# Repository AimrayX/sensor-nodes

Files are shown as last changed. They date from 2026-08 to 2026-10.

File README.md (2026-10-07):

# sensor-nodes

ESP32-based environmental sensor nodes for home automation, publishing MQTT state updates for room-level monitoring.

This project is designed for a small cluster of battery/USB-powered ESP32-C6 nodes that measure indoor or outdoor conditions and report them to an MQTT broker for use in dashboards, automations, or home assistant-style workflows.

## Features

- ESP32-C6 firmware built with PlatformIO and Arduino
- MQTT publishing over Wi-Fi
- OTA firmware updates for selected nodes
- Watchdog-based reboot protection for silent failures
- Support for multiple sensor combinations in separate build environments
- Native host-side unit tests for payload logic

## Hardware configurations

The repository currently includes two primary node variants:

### 1. Bedroom node: BME688 + SCD41

- BME688 environmental sensor
- SCD41 CO2 sensor
- Publishes to: `flat/bedroom/state`
- Build target: `node_bme688_scd41`
- OTA target: `node_bme688_scd41_ota`

### 2. Balcony node: BME280 + PMSA003I

- BME280 temperature / humidity / pressure sensor
- PMSA003I particulate matter sensor
- Publishes to: `flat/balcony/state`
- Build target: `node_pmsa_bme280`
- OTA target: `node_pmsa_bme280_ota`

## Project structure

```text
.
├── .vscode/
├── include/
├── lib/
├── src/
│   ├── connection_handler.cpp
│   ├── connection_handler.h
│   ├── i2c_scanner.cpp
│   ├── main.cpp
│   ├── ota_handler.cpp
│   ├── ota_handler.h
│   ├── payload.cpp
│   ├── payload.h
│   ├── sensors.h
│   ├── sensors_bme280_pmsa003i.cpp
│   ├── sensors_bme688_scd41.cpp
│   ├── watchdog.cpp
│   └── watchdog.h
├── test/
├── .gitignore
├── LICENSE
├── README.md
├── platformio.ini
└── ...
```

## Build and run

### Prerequisites

- PlatformIO Core or VS Code + PlatformIO extension
- An ESP32-C6 compatible board
- Appropriate sensor hardware wired to the board
- A Wi-Fi network and MQTT broker

### Install dependencies

```bash
pio pkg install
```

### Build a specific environment

```bash
pio run -e node_bme688_scd41
pio run -e node_pmsa_bme280
```

### Upload over USB

```bash
pio run -e node_bme688_scd41 -t upload
pio run -e node_pmsa_bme280 -t upload
```

### OTA upload

For OTA builds, create an environment variable with your password before flashing:

```bash
export OTA_PASS="your-ota-password"
pio run -e node_bme688_scd41_ota -t upload
pio run -e node_pmsa_bme280_ota -t upload
```

The project sets OTA host names in `platformio.ini` using the node names:

- `bedroom.local`
- `balcony.local`

## MQTT and node behavior

Each node publishes a structured reading containing the values currently available from its sensors. The common payload model includes:

- PM1, PM2.5, PM10
- CO2
- temperature
- humidity
- pressure

The firmware loops on a 30-second publish interval and reboots after 30 minutes without a successful publish to recover from persistent communication faults.

## Configuration notes

The environment-specific settings live in `platformio.ini` and define:

- board type (`esp32-c6-devkitc-1`)
- sensor libraries
- MQTT topic names
- OTA upload parameters
- build filters for each node variant

Example topic definitions:

```ini
-D NODE_TOPIC='"flat/bedroom/state"'
-D NODE_NAME='"bedroom"'
```

## Testing

The project includes a native host build for unit testing payload logic without a physical board.

```bash
pio test -e native
```

## License

This project is licensed under the GNU General Public License v2.0. See the [LICENSE](LICENSE) file for details.

## Notes

- The `scanner` environment is intended for I2C bus diagnostics during bring-up.
- The `native` environment is helpful for validating logic that does not require board hardware.
- The firmware is intended for local home automation and experimentation, and is configured to fit a small ESP32 sensor network rather than a generic IoT platform.

## Example usage

Once the devices are online, you can subscribe to the topic stream and integrate the readings into dashboards or automation logic.

```bash
mosquitto_sub -h localhost -t 'flat/+/state'
```

This gives you a simple MQTT data source for climate, air quality, and room-state monitoring.

## Repository

- GitHub: https://github.com/AimrayX/sensor-nodes
- Description: ESP32 cluster with environment sensors for home automation via MQTT

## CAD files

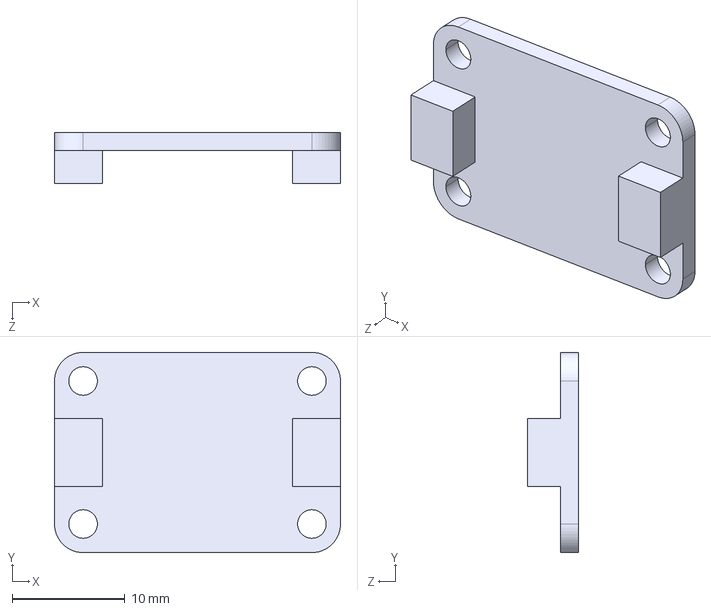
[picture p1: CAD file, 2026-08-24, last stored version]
adafruit-bme688-1.snapshot.2/Adafruit BME688.STEP
25.4 x 17.8 x 4.51 mm

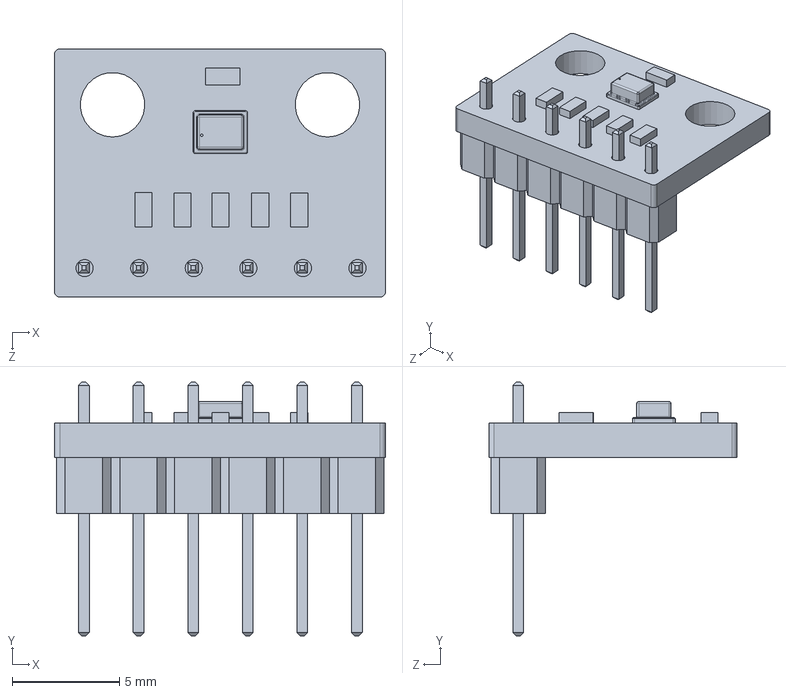
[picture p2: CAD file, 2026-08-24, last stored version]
bme280-model-1.snapshot.2/BME280_SENSOR_MODULE/BME280_SENSOR_MODULE.SLDPRT
15.4 x 11.8 x 11.6 mm

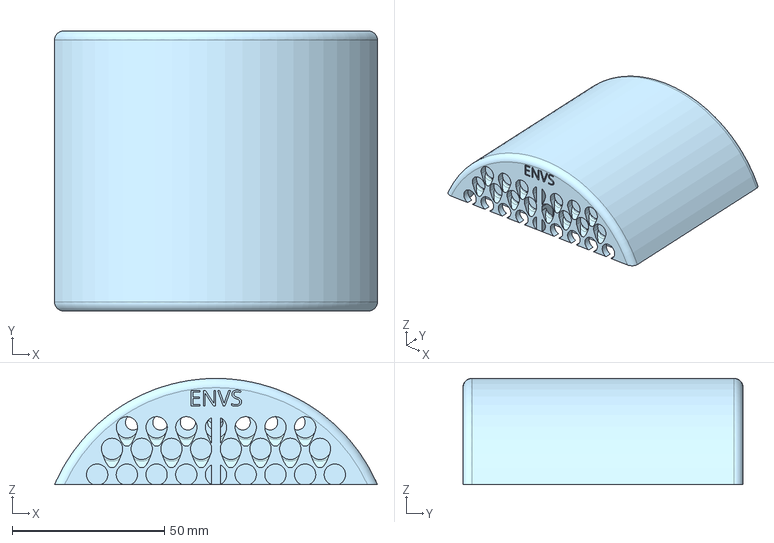
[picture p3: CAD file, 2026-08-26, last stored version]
caseV1.step
106.0 x 92.0 x 34.8 mm

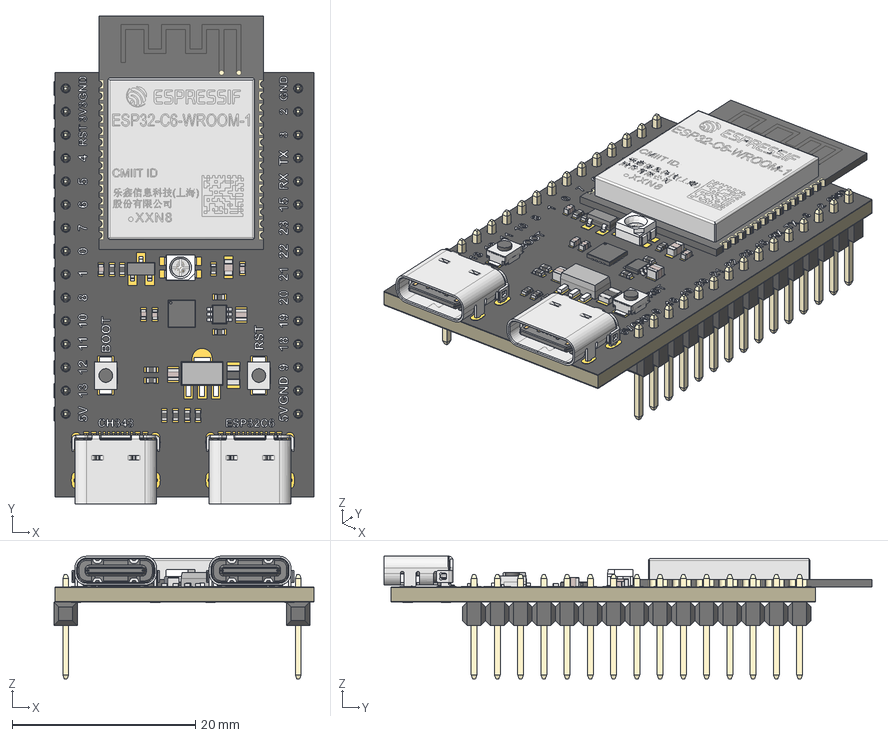
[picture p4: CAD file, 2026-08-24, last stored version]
esp32-c6-wroom-1-1.snapshot.2/ESP32C6.step
28.4 x 53.3 x 13.4 mm
ESP32-C6-WROOM
Chip a 6 pattes
Board
64-copper
1-soldermask
64-soldermask
B3U-1000P(M) v3 x 2
629722000214_Housing x 2
629722000214_Pin1_Top x 2
629722000214_Pin4_Bottom x 2
629722000214_Pin4_Top x 4
629722000214_Pin1_Bottom x 2
629722000214_Pin3_Bottom x 2
629722000214_Pin3_Top x 2
629722000214_Pin2_Top x 2
629722000214_Pin2_Bottom x 2
629722000214_Pin1_Top_mir x 2
629722000214_Pin1_Bottom_mir x 2
629722000214_Pin2_Top_mir x 2
629722000214_Pin2_Bottom_mir x 2
629722000214_Pin3_Top_mir x 2
629722000214_Pin3_Bottom_mir x 2
629722000214_Pin4_Bottom_mir x 2
629722000214_Shielding2 x 2
629722000214_Shielding x 2
9216695.f3d x 4
9216912.f3d x 2
9216932.f3d
5576505.f3d x 11
5576561.f3d
cover
housing
base x 2
SOT89
SOT23
1-copper
Silkscreen

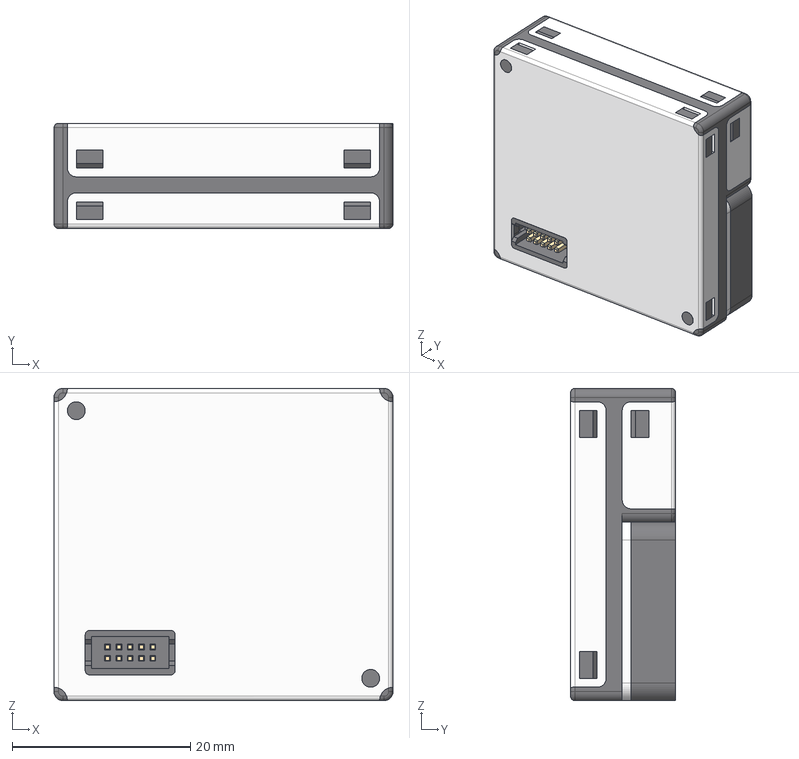
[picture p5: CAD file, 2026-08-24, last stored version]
plantower-pmsa003i-digital-laser-dust-sensor-1.snapshot.2/PM2.5 Air Quality Sensor with I2C Interface - PMSA003I v7.step
38.0 x 11.8 x 35.0 mm

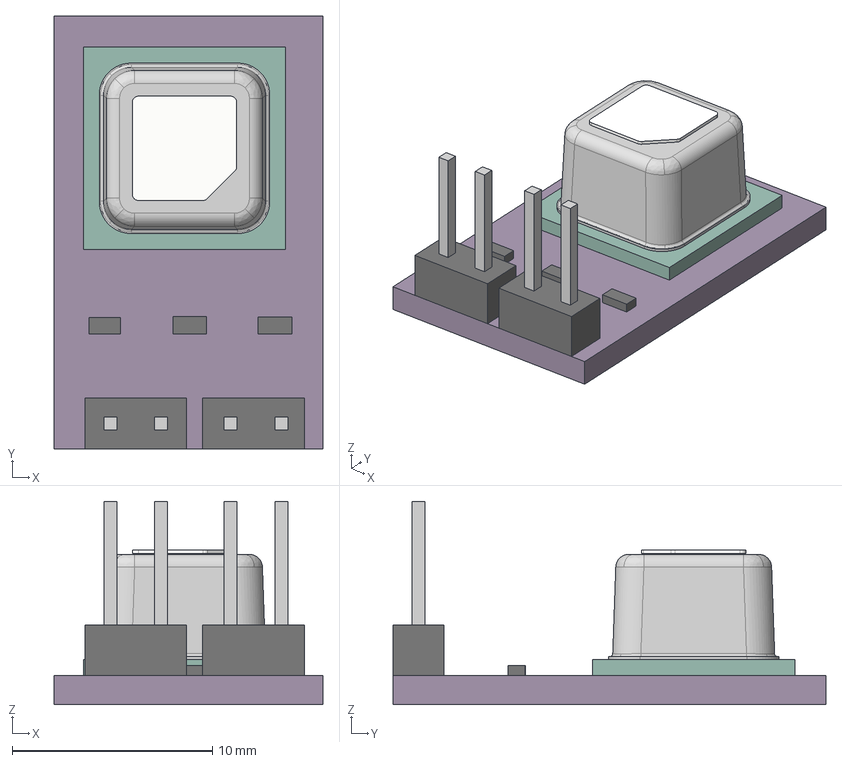
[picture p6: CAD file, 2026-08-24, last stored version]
sensirion-scd40-scd41-1.snapshot.26/scd40 v7.step
13.4 x 21.6 x 10.1 mm
Komponente1
Komponente1 (1)
Komponente2
Komponente3

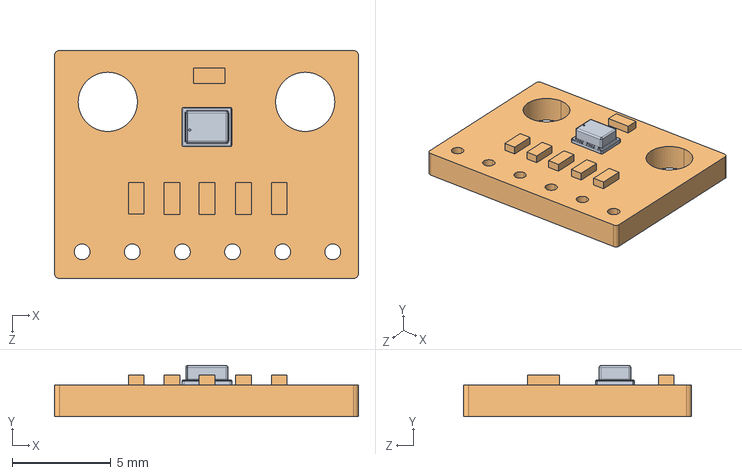
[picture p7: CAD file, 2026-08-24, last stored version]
bme280-model-1.snapshot.2/BME280_SENSOR_MODULE.STEP
15.4 x 2.60 x 11.6 mm

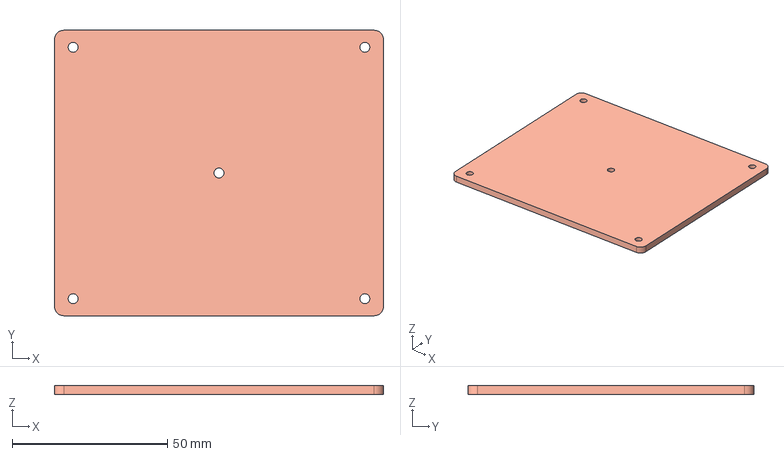
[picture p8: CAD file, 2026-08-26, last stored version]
lidV1.step
106.0 x 92.0 x 3.00 mm

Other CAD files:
bme280-model-1.snapshot.2/BME280_SENSOR_MODULE_WITH_HEADER.STEP
lid.step
case.step
adafruit-bme688-1.snapshot.2/Adafruit BME688.SLDPRT
plantower-pmsa003i-digital-laser-dust-sensor-1.snapshot.2/PM2.5 Air Quality Sensor with I2C Interface - PMSA003I v7.stl
sensirion-scd40-scd41-1.snapshot.26/scd40 v7.3mf

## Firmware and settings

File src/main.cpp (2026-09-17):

#include <Arduino.h>
#include <Wire.h>
#include <esp_task_wdt.h>
#include <esp_system.h>

#include "sensors.h"
#include "connection_handler.h"
#include "ota_handler.h"
#include "watchdog.h"

static constexpr unsigned long PUBLISH_INTERVAL_MS = 30000;
static constexpr unsigned long MAX_SILENCE_MS = 30UL * 60UL * 1000UL;

static unsigned long lastGoodPublish = 0;

void setup() {
  Serial.begin(115200);
  while (!Serial && millis() < 5000) delay(10);
  delay(500);
  Serial.printf("%s booting, reset reason %d\n", NODE_NAME, esp_reset_reason());

  Wire.begin(SDA, SCL);
  if (!sensors_init(Wire)) Serial.println("sensors_init reported failure");

  connection_init();
  ota_init(NODE_NAME);
  watchdog_init();
  lastGoodPublish = millis();

  Serial.printf("TWDT subscribed: %s\n",
                esp_task_wdt_status(NULL) == ESP_OK ? "yes" : "NO");
}

void loop() {
  ota_loop();
  if (ota_in_progress()) return;

  esp_task_wdt_reset();
  connection_loop();
  sensors_tick();

  static unsigned long lastMsg = 0;
  unsigned long now = millis();

  if (now - lastMsg > PUBLISH_INTERVAL_MS) {
    lastMsg = now;
    Reading r;
    if (sensors_read(r) && publish(NODE_TOPIC, r)) {
      lastGoodPublish = now;
      sensors_mark_sent();
    }
  }

  if (now - lastGoodPublish > MAX_SILENCE_MS) {
    Serial.println("30 min without a publish - rebooting");
    Serial.flush();
    delay(100);
    ESP.restart();
  }
}

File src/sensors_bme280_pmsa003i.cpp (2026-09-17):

#include "sensors.h"

#include <Adafruit_BME280.h>
#include <Adafruit_PM25AQI.h>

static Adafruit_BME280 bme;
static Adafruit_PM25AQI aqi = Adafruit_PM25AQI();
static bool bmeOk = false;
static bool aqiOk = false;

// The PM sensor is duty-cycled: the fan is the wear item, so it runs for
// ~38 s out of every 5 min. Wake -> WarmingUp (fan stabilises, output is
// not trustworthy) -> Sampling (poll repeatedly, keep the last good frame)
// -> Sleeping.
enum class PmState { Sleeping, WarmingUp, Sampling };
static PmState pmState = PmState::WarmingUp;

static unsigned long pmCycleStart = 0;  // when the current 5 min period began
static unsigned long pmPhaseStart = 0;  // when the current phase began
static unsigned long pmLastPoll   = 0;  // last aqi.read() attempt

static constexpr unsigned long PM_INTERVAL_MS = 5UL * 60UL * 1000UL;
static constexpr unsigned long PM_WARMUP_MS   = 30UL * 1000UL;
static constexpr unsigned long PM_SAMPLE_MS   = 8UL * 1000UL;
static constexpr unsigned long PM_POLL_MS     = 1000UL;
static constexpr uint8_t       PM_MIN_FRAMES  = 2;

static PM25_AQI_Data pmLastFrame;
static uint8_t       pmGoodFrames = 0;

static float pmCache1 = NAN, pmCache25 = NAN, pmCache10 = NAN;
static unsigned long pmCacheAt = 0;
static bool  pmFresh  = false;

bool sensors_init(TwoWire &wire) {
  pinMode(PIN_PM_SET, OUTPUT);
  digitalWrite(PIN_PM_SET, HIGH);
  delay(100);

  Serial.println(F("Setting up BME280"));

  bmeOk = bme.begin(BME280_ADDRESS, &wire);
  if (!bmeOk) bmeOk = bme.begin(BME280_ADDRESS_ALTERNATE, &wire);
  if (bmeOk) {
    // Forced mode at 30 s intervals, so power is irrelevant - buy noise
    // reduction with oversampling instead. IIR stays OFF: in forced mode
    // the filter state persists between measurements, so with a 30 s gap
    // it would smear temperature over several minutes, and temperature is
    // a control input.
    bme.setSampling(Adafruit_BME280::MODE_FORCED,
                    Adafruit_BME280::SAMPLING_X2,   // temperature
                    Adafruit_BME280::SAMPLING_X16,  // pressure
                    Adafruit_BME280::SAMPLING_X16,  // humidity
                    Adafruit_BME280::FILTER_OFF);
  } else {
    Serial.println("Could not find a valid BME280 sensor, check wiring!");
  }

  Serial.println("BME280 setup finished");
  Serial.println();

  Serial.println(F("Setting up PMSA003I"));
  aqiOk = aqi.begin_I2C(&wire);
  if (!aqiOk) {
    Serial.println("Could not find PMSA003I sensor, check wiring!");
  }
  Serial.println("PMSA003I setup finished");
  Serial.println();

  // Start in WarmingUp so the first reading arrives ~38 s after boot
  pmCycleStart = millis();
  pmPhaseStart = millis();
  pmState = PmState::WarmingUp;

  // Degrade rather than fail: temperature/humidity/pressure alone is still
  // a useful node. PM availability is reported separately above.
  return bmeOk;
}

void sensors_tick() {
  const unsigned long now = millis();

  switch (pmState) {
    case PmState::Sleeping:
      if (now - pmCycleStart >= PM_INTERVAL_MS) {
        digitalWrite(PIN_PM_SET, HIGH);
        pmCycleStart = now;
        pmPhaseStart = now;
        pmState = PmState::WarmingUp;
      }
      break;

    case PmState::WarmingUp:
      if (now - pmPhaseStart >= PM_WARMUP_MS) {
        pmGoodFrames = 0;
        pmLastPoll   = now - PM_POLL_MS;  // poll immediately on entry
        pmPhaseStart = now;
        pmState      = PmState::Sampling;
      }
      break;

    case PmState::Sampling:
      // The module emits a frame about once per second; polling faster just
      // re-reads the same buffer and hogs the I2C bus shared with the BME280.
      if (now - pmLastPoll >= PM_POLL_MS) {
        pmLastPoll = now;
        PM25_AQI_Data d;
        if (aqiOk && aqi.read(&d)) {   // read() validates the checksum
          pmLastFrame = d;
          pmGoodFrames++;
        }
      }

      if (now - pmPhaseStart >= PM_SAMPLE_MS) {
        if (pmGoodFrames >= PM_MIN_FRAMES) {
          // _env is the atmospheric-environment output (vs _standard, CF=1).
          // Note the naming: pm10_env is PM1.0, pm100_env is PM10.
          pmCache1  = pmLastFrame.pm10_env;
          pmCache25 = pmLastFrame.pm25_env;
          pmCache10 = pmLastFrame.pm100_env;
          pmCacheAt = now;
          pmFresh   = true;
        } else {
          Serial.printf("PMSA003I: only %u good frame(s), skipping cycle\n",
                        pmGoodFrames);
        }
        digitalWrite(PIN_PM_SET, LOW);
        pmPhaseStart = now;
        pmState      = PmState::Sleeping;
      }
      break;
  }
}

bool sensors_read(Reading& out) {
  bool any = false;

  if (bmeOk) {
    if (bme.takeForcedMeasurement()) {
      out.temp     = bme.readTemperature();
      out.humidity = bme.readHumidity();
      out.pressure = bme.readPressure();
      any = true;
    } else {
      Serial.println("BME280 forced measurement failed");
    }
  }

  // Offered until sensors_mark_sent() confirms delivery, but never longer
  // than one cycle - a value older than that is superseded, not retried.
  if (pmFresh) {
    if (millis() - pmCacheAt < PM_INTERVAL_MS) {
      out.pm1  = pmCache1;
      out.pm25 = pmCache25;
      out.pm10 = pmCache10;
      any = true;
    } else {
      pmFresh = false;
    }
  }

  return any;
}

void sensors_mark_sent() {
  pmFresh = false;
}

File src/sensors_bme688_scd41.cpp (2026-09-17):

#include "sensors.h"

#include <Adafruit_BME680.h>
#include <SensirionI2cScd4x.h>

static Adafruit_BME680 bme(&Wire);
static SensirionI2cScd4x scd;

static bool bmeOk = false;
static bool scdOk = false;

static float co2Cache = NAN;
static unsigned long co2CacheAt = 0;
static bool  co2Fresh = false;

static unsigned long lastScdPoll = 0;
static constexpr unsigned long SCD_POLL_MS = 1000;
static constexpr unsigned long CO2_MAX_AGE_MS = 60UL * 1000UL;

bool sensors_init(TwoWire &wire) {
  Serial.println(F("Setting up BME688"));

  bmeOk = bme.begin(BME68X_DEFAULT_ADDRESS, true);   // 0x77
  if (!bmeOk) bmeOk = bme.begin(0x76, true);         // common alternate
  if (!bmeOk) {
    Serial.println("BME688 not found, continuing without it");
  } else {
    bme.setTemperatureOversampling(BME680_OS_2X);
    bme.setHumidityOversampling(BME680_OS_16X);
    bme.setPressureOversampling(BME680_OS_16X);
    bme.setIIRFilterSize(BME680_FILTER_SIZE_0);
    bme.setGasHeater(0, 0);   // gas heater off: no BSEC, no IAQ output
  }

  Serial.println("BME688 setup finished");
  Serial.println();

  Serial.println(F("Setting up SCD41"));

  scdOk = true;
  scd.begin(wire, 0x62);
  delay(30);

  scd.wakeUp();
  delay(30);

  if (scd.stopPeriodicMeasurement()) {
    Serial.println("SCD41 stopPeriodicMeasurement returned an error (ok if idle)");
  }
  delay(500);   // datasheet: stop takes up to 500 ms to complete

  if (scd.reinit()) {
    Serial.println("SCD41 reinit() failed");
    scdOk = false;
  }

  uint64_t serialNumber = 0;
  if (scd.getSerialNumber(serialNumber)) {
    Serial.println("SCD41 getSerialNumber() failed");
    scdOk = false;
  } else {
    Serial.printf("SCD41 serial number: %04X%04X%04X\n",
                  (unsigned)((serialNumber >> 32) & 0xFFFF),
                  (unsigned)((serialNumber >> 16) & 0xFFFF),
                  (unsigned)(serialNumber & 0xFFFF));
  }

  if (scd.startPeriodicMeasurement()) {
    Serial.println("SCD41 startPeriodicMeasurement() failed");
    scdOk = false;
  }

  Serial.println("SCD41 setup finished");
  Serial.println();

  // Degrade rather than fail, same as the BME280 variant.
  return bmeOk || scdOk;
}

void sensors_tick() {
  if (!scdOk) return;

  const unsigned long now = millis();
  if (now - lastScdPoll < SCD_POLL_MS) return;   // don't hammer the I2C bus
  lastScdPoll = now;

  bool ready = false;
  // Sensirion's generated drivers return int16_t, 0 == NO_ERROR.
  if (scd.getDataReadyStatus(ready) != 0 || !ready) return;

  uint16_t co2 = 0;
  float t = 0.0f, rh = 0.0f;
  if (scd.readMeasurement(co2, t, rh) == 0 && co2 != 0) {
    co2Cache   = co2;      // a CO2 of 0 means the sample is invalid
    co2CacheAt = now;
    co2Fresh   = true;
  }
}

bool sensors_read(Reading& out) {
  bool any = false;

  if (bmeOk) {
    if (bme.performReading()) {
      out.temp     = bme.temperature;
      out.humidity = bme.humidity;
      out.pressure = bme.pressure;
      any = true;
    } else {
      Serial.println("BME688 performReading() failed");
    }
  }

  // A new CO2 sample lands every 5 s, so retrying a failed publish matters
  // less here than for PM - but keep the interface identical across variants.
  if (co2Fresh) {
    if (millis() - co2CacheAt < CO2_MAX_AGE_MS) {
      out.co2 = co2Cache;
      any = true;
    } else {
      co2Fresh = false;
    }
  }

  return any;
}

void sensors_mark_sent() {
  co2Fresh = false;
}

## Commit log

2026-08-24 repo switch
2026-08-25 started implementing sensor setup and reading logic
2026-08-25 small revision on sensor measurement
2026-08-26 small bme280 reading code fix
    [case.step, caseV1.step, lid.step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]
2026-08-26 passed Wired deliberatly
2026-09-17 state machine and more little fixes
    [main.cpp, sensors_bme280_pmsa003i.cpp, sensors_bme688_scd41.cpp]
2026-09-24 project restructure
    [Adafruit BME688.SLDPRT, Adafruit BME688.STEP, BME280_SENSOR_MODULE.SLDPRT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]
2026-10-07 Refresh the project README with project overview, hardware setup, build instructions, MQTT usage, and configuration details for the sensor-nodes firmware.
